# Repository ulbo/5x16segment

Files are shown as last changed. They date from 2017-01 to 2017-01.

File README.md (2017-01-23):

Linkable 5x16-Segment LED Display Module
========================================

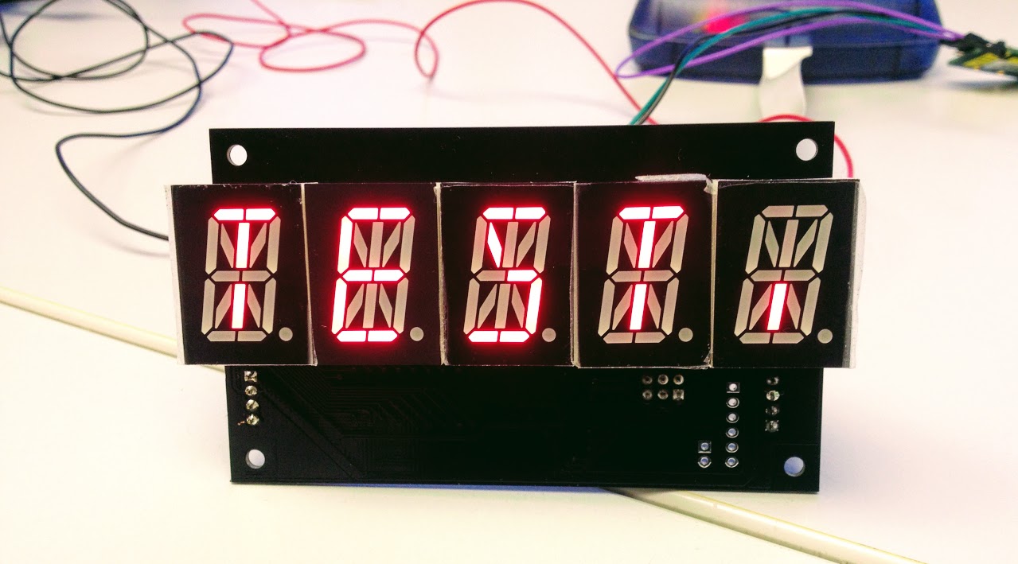
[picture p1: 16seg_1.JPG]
Single 5x16 display board

Single display board

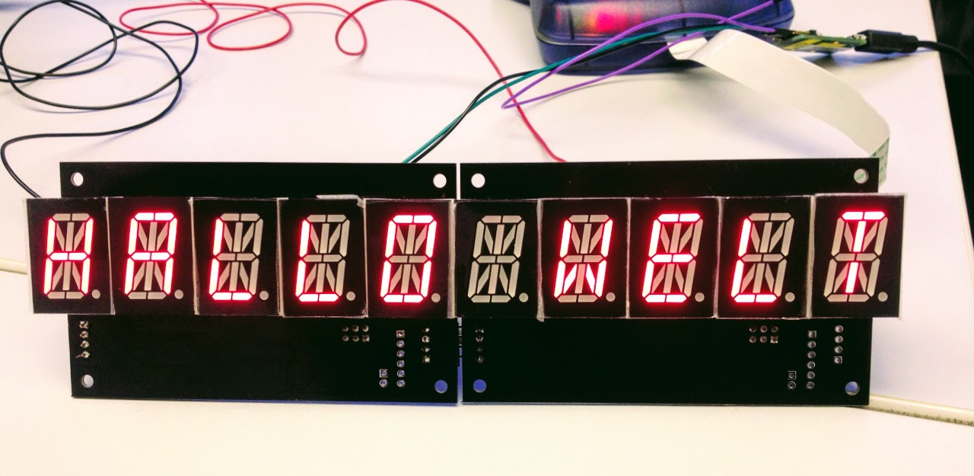
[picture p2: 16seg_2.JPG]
Two boards connected

Two boards connected to form a 10 character display

Hardware
--------

The module uses an Atmel ATmega32 MCU to control all LED segments. Input is done via RS232 interface with a voltage level of 5V.

Supply voltage: 5VDC, max. 200mA per module

Board layout is designed using KiCAD. It is tested for LDS8103-AX 16-segment displays (see /board/lds-8103.jpg), but should work with any common-cathode 16-segment display with same mechanical dimensions and pinout, e.g. Kingbright PSC08-11GWA. Because all pins, except the cathode at pin 11, are directly controlled by the MCU, LEDs with other pinouts can be used with adapted firmware.

Please note: The LED displays are soldered on the opposite board site than the ATmega.

Firmware
--------

Communication to modules is unidirectional with _9600 bps, 8N1_. Modules are daisy-chained, the RS232 output of the leftmost module is connected to the input of its right neighbour. Every module displays all incoming ASCII characters. If its 5-character memory is full, it passes all further incoming chars to its output, where it is received by the next display.

There are a few control characters, which are always passed immediately:

 * 0x01..0x06 : set display brightness, 1 is lowest
 * 0x10, 0x13 : <CR> or <LF> character reset the "cursor" to leftmost position

Compilation under Windows by Atmel Studio 7, Project file: /firmware/16segment.atsln
For Linux, /firmware/makefile is provided, see instructions there.

Firmware is flashed using the standard 6-pin ISP connector. File is /firmware/Release/16segment.hex

Fuse settings:

 * BODLEVEL = 2.7 V,
 * CLKSEL = Ext. Crystal, 8.0-16.0 MHz, 16K CK, 65ms start up time
 * BOOTSZ = 256 words
 * SPIEN enabled
 * TAGEN disabled
 * others: disabled

Character Set
-------------

 * 0x20 .. 0x7F : normal ASCII characters, small caps are currently rendered uppercase (may be changed in future release)
 * 0x80 .. 0x9F : a few "graphic" characters, arrows, etc.
 * 0xA0 .. 0xff : same as 0x20..0x7f, but with decimal point on

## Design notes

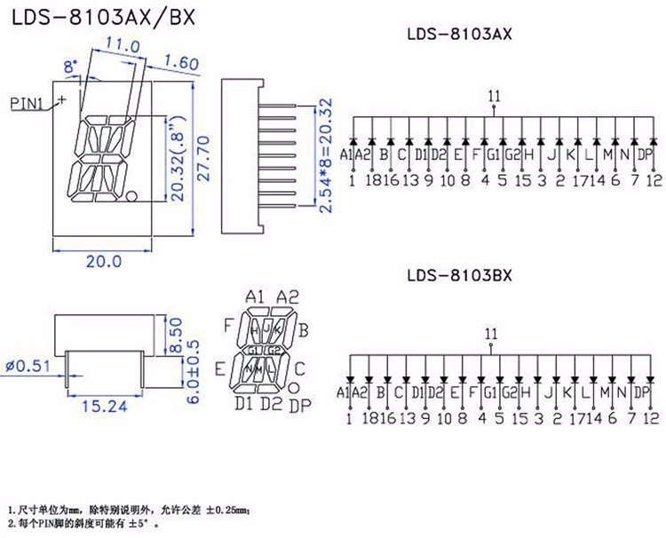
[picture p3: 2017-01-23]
board/lds-8103.jpg

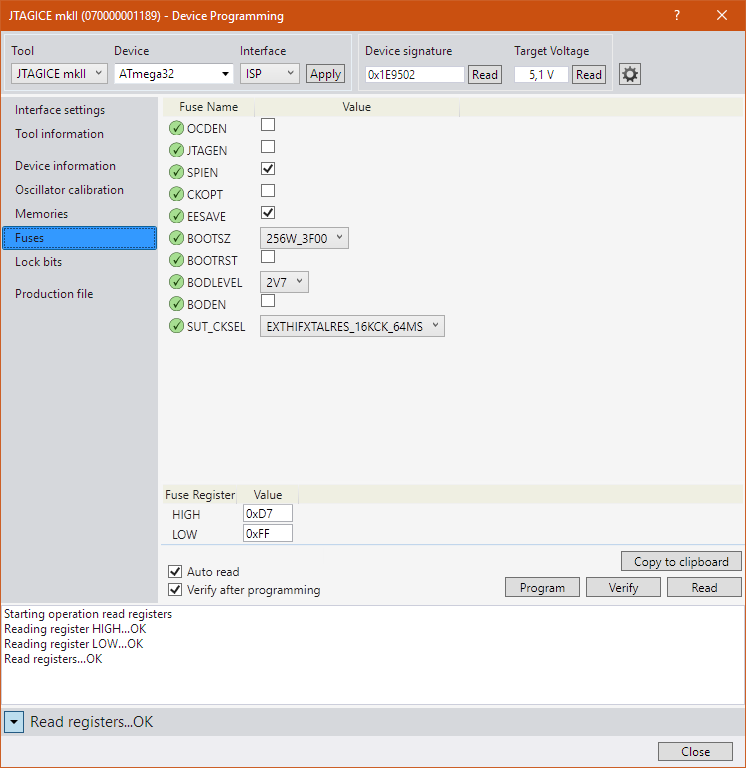
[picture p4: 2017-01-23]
firmware/16seg_fuses.png

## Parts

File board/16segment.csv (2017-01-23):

ID | Bezeichner | Gehäuse | Stückzahl | Bezeichnung | Anbieter und Ref.
1 | LED5,LED2,LED4,LED1,LED3 | LDS8103-AX_rev | 5 | LDS-8103AX
2 | R2,R3,R4,R5,R6,R7,R8,R9,R10,R11,R12,R13,R14,R15,R16,R17,R18 | R_0603_HandSoldering | 17 | 180
3 | C1,C2 | C_0805_HandSoldering | 2 | 15pF
4 | C3,C4,C5,C6,C7 | C_0603_HandSoldering | 5 | 100nF
5 | C8 | C_1210_HandSoldering | 1 | 10uF
6 | IC1 | TQFP-44_10x10mm_Pitch0.8mm | 1 | ATMEGA16-A
7 | P1 | Pin_Header_Straight_1x06 | 1 | CONN_01X06
8 | P2 | Pin_Header_Straight_2x03 | 1 | AVR ISP
9 | P3 | Pin_Header_Angled_1x04 | 1 | DATA_IN
10 | P4 | Pin_Header_Angled_1x04 | 1 | DATA_OUT
11 | Q1,Q2,Q3,Q4,Q5 | SOT-23_Handsoldering | 5 | BC817-40
12 | R1 | R_0603_HandSoldering | 1 | 10k
13 | R19,R20,R21,R22,R23 | R_0603_HandSoldering | 5 | 470
14 | X1 | Q_49U3HMS | 1 | 16 MHz
15 | REF**,REF**,REF**,REF** | MountingHole_3.2mm_M3 | 4 | MountingHole_3.2mm_M3
16 | P5 | Pin_Header_Straight_1x02 | 1 | CONN_01X02

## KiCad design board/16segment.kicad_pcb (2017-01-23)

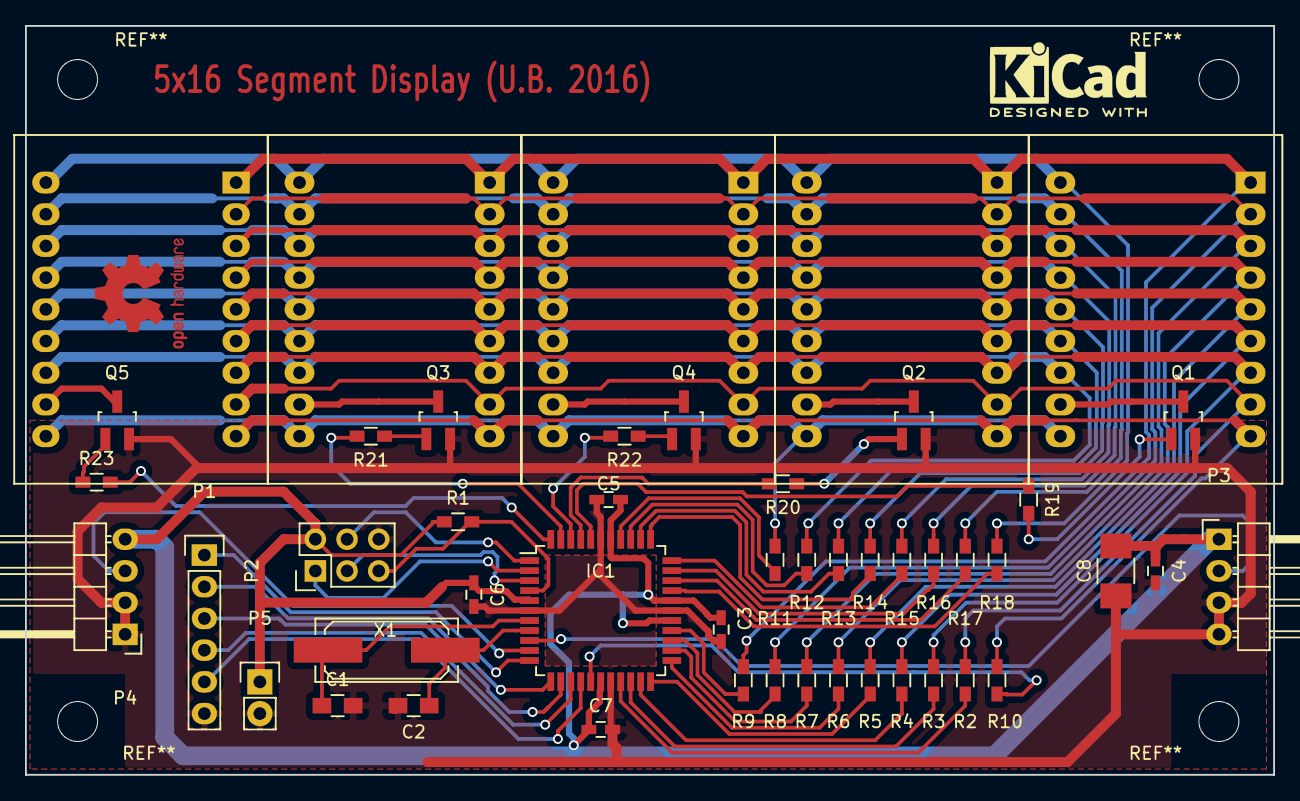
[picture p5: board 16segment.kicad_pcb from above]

Board: 2 copper layers, 100.0 x 60.0 mm, 48 parts (0 on the bottom side), 64 nets.

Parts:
C1, C2: 15pF; C_0805_HandSoldering
C3, C4, C5, C6, C7: 100nF; C_0603_HandSoldering
C8: 10uF; C_1210_HandSoldering
IC1: ATMEGA16-A; TQFP-44_10x10mm_Pitch0.8mm
LED1, LED2, LED3, LED4, LED5: LDS-8103AX; LDS8103-AX_rev
P1: CONN_01X06; Pin_Header_Straight_1x06
P2: AVR ISP; Pin_Header_Straight_2x03
P3: DATA_IN; Pin_Header_Angled_1x04
P4: DATA_OUT; Pin_Header_Angled_1x04
P5: CONN_01X02; Pin_Header_Straight_1x02
Q1, Q2, Q3, Q4, Q5: BC817-40; SOT-23_Handsoldering
R1: 10k; R_0603_HandSoldering
R2, R3, R4, R5, R6, R7, R8, R9, R10, R11, R12, R13, R14, R15, R16, R17, R18: 180; R_0603_HandSoldering
R19, R20, R21, R22, R23: 470; R_0603_HandSoldering
X1: 16 MHz; Q_49U3HMS

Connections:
/LED_1: IC1.40, R19.2
/LED_2: IC1.41, R20.2
/LED_3: IC1.42, R22.2
/LED_4: IC1.43, R21.2
/LED_5: IC1.44, R23.2
/LED_A1: LED1.1, LED2.1, LED3.1, LED4.1, LED5.1, R9.1
/LED_A2: LED1.18, LED2.18, LED3.18, LED4.18, LED5.18, R18.1
/LED_B: LED1.16, LED2.16, LED3.16, LED4.16, LED5.16, R16.1
/LED_C: LED1.13, LED2.13, LED3.13, LED4.13, LED5.13, R13.1
/LED_D1: LED1.9, LED2.9, LED3.9, LED4.9, LED5.9, R10.1
/LED_D2: LED1.10, LED2.10, LED3.10, LED4.10, LED5.10, R11.1
/LED_DP: LED1.12, LED2.12, LED3.12, LED4.12, LED5.12, R12.1
/LED_E: LED1.8, LED2.8, LED3.8, LED4.8, LED5.8, R2.1
/LED_F: LED1.4, LED2.4, LED3.4, LED4.4, LED5.4, R6.1
/LED_G1: LED1.5, LED2.5, LED3.5, LED4.5, LED5.5, R5.1
/LED_G2: LED1.15, LED2.15, LED3.15, LED4.15, LED5.15, R15.1
/LED_H: LED1.3, LED2.3, LED3.3, LED4.3, LED5.3, R7.1
/LED_J: LED1.2, LED2.2, LED3.2, LED4.2, LED5.2, R8.1
/LED_K: LED1.17, LED2.17, LED3.17, LED4.17, LED5.17, R17.1
/LED_L: LED1.14, LED2.14, LED3.14, LED4.14, LED5.14, R14.1
/LED_M: LED1.6, LED2.6, LED3.6, LED4.6, LED5.6, R4.1
/LED_N: LED1.7, LED2.7, LED3.7, LED4.7, LED5.7, R3.1
/MISO: IC1.2, P2.1
/MOSI: IC1.1, P2.4
/RESET: IC1.4, P2.5, R1.2
/RxD: IC1.9, P3.2
/SCK: IC1.3, P2.3
/TxD: IC1.10, P4.3
GND: C1.2, C2.2, C3.2, C4.2, C5.2, C6.2, C7.2, C8.2, IC1.6, IC1.18, IC1.28, IC1.39, P1.6, P2.6, P3.3, P3.4, P4.1, P4.2, P5.2, Q1.2, Q2.2, Q3.2, Q4.2, Q5.2
unnamed: C1.1, IC1.7, X1.1
unnamed: C2.1, IC1.8, X1.2
unnamed: IC1.11, P1.1
unnamed: IC1.12, P1.2
unnamed: IC1.13, P1.3
unnamed: IC1.14, P1.4
unnamed: IC1.15, P1.5
unnamed: IC1.16, R10.2
unnamed: IC1.19, R2.2
unnamed: IC1.20, R3.2
unnamed: IC1.21, R4.2
unnamed: IC1.22, R5.2
unnamed: IC1.23, R6.2
unnamed: IC1.24, R7.2
unnamed: IC1.25, R8.2
unnamed: IC1.26, R9.2
unnamed: IC1.30, R18.2
unnamed: IC1.31, R17.2
unnamed: IC1.32, R16.2
unnamed: IC1.33, R15.2
unnamed: IC1.34, R14.2
unnamed: IC1.35, R13.2
unnamed: IC1.36, R12.2
unnamed: IC1.37, R11.2
unnamed: LED1.11, Q1.3
unnamed: LED2.11, Q2.3
unnamed: LED3.11, Q3.3
unnamed: LED4.11, Q4.3
unnamed: LED5.11, Q5.3
unnamed: Q1.1, R19.1
unnamed: Q2.1, R20.1
unnamed: Q3.1, R21.1
unnamed: Q4.1, R22.1
unnamed: Q5.1, R23.1
VCC: C3.1, C4.1, C5.1, C6.1, C7.1, C8.1, IC1.5, IC1.17, IC1.27, IC1.29, IC1.38, P2.2, P3.1, P4.4, P5.1, R1.1

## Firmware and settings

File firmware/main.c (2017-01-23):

/**********************  P r o g r a m  -  M o d u l e ***********************/
/*!
 *        \file  main.c
 *
 *      \author  Ulrich Bogensperger
 *        $Date: $
 *    $Revision: $
 *
 *        \brief
 *
 *          Firmware for 5x16 segment display board
 *
 *          Chip type           : ATmega16 or ATmega32
 *          Clock frequency     : 16.000 MHz
 *
 *          Fuse settings: BODLEVEL = 2.7 V,
 *                         CLKSEL = Ext. Crystal, 8.0-16.0 MHz, 16K CK, 65ms start up time
 *                         BOOTSZ = 256 words
 *                         SPIEN enabled
 *                         JTAGEN disabled
 *                         others: disabled
 *
 *          Compiler (Atmel Studio 7):
 *              avr-gcc (AVR_8_bit_GNU_Toolchain_3.5.0_1662) 4.9.2
 *
 *          Compiler options:
 *              -Wall -funsigned-char -funsigned-bitfields -ffunction-sections 
 *              -fdata-sections -fpack-struct -fshort-enums -mmcu=atmega32 -Os 
 *
 *          Include Path:
 *              - C:\Program Files (x86)\Atmel\Studio\7.0\Packs\atmel\ATmega_DFP\1.0.90\include
 *
 *          Library Path:
 *              - C:\Program Files (x86)\Atmel\Studio\7.0\
 *
 *-------------------------------[ History ]---------------------------------
 *
 * $Log: $
 *
 *
 *---------------------------------------------------------------------------
 * (c) Copyright 2016, 2017 by Ulrich Bogensperger, Nuernberg, Germany
 ****************************************************************************/

#include "16seg.h"


/*--------------------------------------+
|   DEFINES                             |
+--------------------------------------*/
#define BRIGHT_STEPS        6                   /**< number of brightness steps */
#define BRIGHT_CT_MAX       (1 << BRIGHT_STEPS) /**< brightness counter max */

/*--------------------------------------+
|   TYPEDEFS                            |
+--------------------------------------*/
/* none */

/*--------------------------------------+
|   PROTOTYPES                          |
+--------------------------------------*/
/* none */

/*--------------------------------------+
|   GLOBALS                             |
+--------------------------------------*/
volatile uint16_t G_tick;               /**< system tick, incremented every 10ms */

uint8_t G_led_buffer[NLED][3];          /**< Buffer for LED segments to light. 
                                             Contains the values to be written to GPIOs. */

volatile uint8_t G_brightness = 5;      /**< display brightness 0..5 */
volatile uint8_t G_write_pos;           /**< current write position in G_led_buffer */

/** character table for 16 segment LED display */

/* 
 Port A:   7  6  5  4  3  2  1  0   Port C:  7  6  5  4  3  2  1  0   Port D:  7
 Segment:  A2 K  B G2  L  C DP D2            A1 J  H  F G1  M  N  E            D1
*/

const uint8_t G_chartable[0x80][3] PROGMEM = {
    { 0b00000000, 0b00000000, 0b00000000 },     /* 0x20  <space> */
    { 0b11000000, 0b10100100, 0b00000000 },     /* 0x21  ! */
    { 0b00000000, 0b01010000, 0b00000000 },     /* 0x22  " */
    { 0b00110101, 0b01001100, 0b10000000 },     /* 0x23  # */
    { 0b10010101, 0b11011100, 0b10000000 },     /* 0x24  $ */
    { 0b01011100, 0b00111010, 0b00000000 },     /* 0x25  % */
    { 0b11001101, 0b10101001, 0b10000000 },     /* 0x26  & */
    { 0b00000000, 0b01000000, 0b00000000 },     /* 0x27  ' */
    { 0b01001000, 0b00000000, 0b00000000 },     /* 0x28  ( */
    { 0b00000000, 0b00100010, 0b00000000 },     /* 0x29  ) */
    { 0b01011000, 0b01101110, 0b00000000 },     /* 0x2a  * */
    { 0b00010000, 0b01001100, 0b00000000 },     /* 0x2b  + */
    { 0b00000000, 0b00000010, 0b00000000 },     /* 0x2c  , */
    { 0b00010000, 0b00001000, 0b00000000 },     /* 0x2d  - */
    { 0b00000000, 0b00000100, 0b00000000 },     /* 0x2e  . */
    { 0b01000000, 0b00000010, 0b00000000 },     /* 0x2f  / */

    { 0b11100101, 0b10010011, 0b10000000 },     /* 0x30  0 */
    { 0b00100100, 0b00000000, 0b00000000 },     /* 0x31  1 */
    { 0b10110001, 0b10001001, 0b10000000 },     /* 0x32  2 */
    { 0b10110101, 0b10001000, 0b10000000 },     /* 0x33  3 */
    { 0b00110100, 0b00011000, 0b00000000 },     /* 0x34  4 */
    { 0b10010101, 0b10011000, 0b10000000 },     /* 0x35  5 */
    { 0b10010101, 0b10011001, 0b10000000 },     /* 0x36  6 */
    { 0b10100100, 0b10010000, 0b00000000 },     /* 0x37  7 */
    { 0b10110101, 0b10011001, 0b10000000 },     /* 0x38  8 */
    { 0b10110101, 0b10011000, 0b10000000 },     /* 0x39  9 */
    { 0b00000000, 0b01000100, 0b00000000 },     /* 0x3a  : */
    { 0b00000000, 0b01000010, 0b00000000 },     /* 0x3b  ; */
    { 0b01000001, 0b00000010, 0b10000000 },     /* 0x3c  < */
    { 0b00010001, 0b00001000, 0b10000000 },     /* 0x3d  = */
    { 0b00001001, 0b00100000, 0b10000000 },     /* 0x3e  > */
    { 0b10110000, 0b10000100, 0b00000000 },     /* 0x3f  ? */

    { 0b00100101, 0b10010101, 0b00000000 },     /* 0x40  @ */
    { 0b10110100, 0b10011001, 0b00000000 },     /* 0x41  A */
    { 0b11010101, 0b10011001, 0b10000000 },     /* 0x42  B */
    { 0b10000001, 0b10010001, 0b10000000 },     /* 0x43  C */
    { 0b10100101, 0b11000100, 0b10000000 },     /* 0x44  D */
    { 0b10010001, 0b10011001, 0b10000000 },     /* 0x45  E */
    { 0b10010000, 0b10011001, 0b00000000 },     /* 0x46  F */
    { 0b10010101, 0b10010001, 0b10000000 },     /* 0x47  G */
    { 0b00110100, 0b00011001, 0b00000000 },     /* 0x48  H */
    { 0b10000001, 0b11000100, 0b10000000 },     /* 0x49  I */
    { 0b00100101, 0b00000001, 0b10000000 },     /* 0x4a  J */
    { 0b01001000, 0b00011001, 0b00000000 },     /* 0x4b  K */
    { 0b00000001, 0b00010001, 0b10000000 },     /* 0x4c  L */
    { 0b01100100, 0b00110001, 0b00000000 },     /* 0x4d  M */
    { 0b00101100, 0b00110001, 0b00000000 },     /* 0x4e  N */
    { 0b10100101, 0b10010001, 0b10000000 },     /* 0x4f  O */

    { 0b10110000, 0b10011001, 0b00000000 },     /* 0x50  P */
    { 0b10101101, 0b10010001, 0b10000000 },     /* 0x51  Q */
    { 0b10111000, 0b10011001, 0b00000000 },     /* 0x52  R */
    { 0b10010101, 0b10100000, 0b10000000 },     /* 0x53  S */
    { 0b10000000, 0b11000100, 0b00000000 },     /* 0x54  T */
    { 0b00100101, 0b00010001, 0b10000000 },     /* 0x55  U */
    { 0b01000000, 0b00010011, 0b00000000 },     /* 0x56  V */
    { 0b00101100, 0b00010011, 0b00000000 },     /* 0x57  W */
    { 0b01001000, 0b00100010, 0b00000000 },     /* 0x58  X */
    { 0b01000000, 0b00100100, 0b00000000 },     /* 0x59  Y */
    { 0b11000001, 0b10000010, 0b10000000 },     /* 0x5a  Z */
    { 0b10000001, 0b01000100, 0b00000000 },     /* 0x5b  [ */
    { 0b00001000, 0b00100000, 0b00000000 },     /* 0x5c  \ */
    { 0b00000000, 0b11000100, 0b10000000 },     /* 0x5d  ] */
    { 0b00000000, 0b00110000, 0b00000000 },     /* 0x5e  ^ */
    { 0b00000001, 0b00000000, 0b10000000 },     /* 0x5f  _ */

    { 0b01000000, 0b00000000, 0b00000000 },     /* 0x60  <backtick> */
    { 0b10110100, 0b10011001, 0b00000000 },     /* 0x61  a */ /* small caps have same glyphs as large caps */
    { 0b11010101, 0b10011001, 0b10000000 },     /* 0x62  b */
    { 0b10000001, 0b10010001, 0b10000000 },     /* 0x63  c */
    { 0b10100101, 0b11000100, 0b10000000 },     /* 0x64  d */
    { 0b10010001, 0b10011001, 0b10000000 },     /* 0x65  e */
    { 0b10010000, 0b10011001, 0b00000000 },     /* 0x66  f */
    { 0b10010101, 0b10010001, 0b10000000 },     /* 0x67  g */
    { 0b00110100, 0b00011001, 0b00000000 },     /* 0x68  h */
    { 0b10000001, 0b11000100, 0b10000000 },     /* 0x69  i */
    { 0b00100101, 0b00000001, 0b10000000 },     /* 0x6a  j */
    { 0b01001000, 0b00011001, 0b00000000 },     /* 0x6b  k */
    { 0b00000001, 0b00010001, 0b10000000 },     /* 0x6c  l */
    { 0b01100100, 0b00110001, 0b00000000 },     /* 0x6d  m */
    { 0b00101100, 0b00110001, 0b00000000 },     /* 0x6e  n */
    { 0b10100101, 0b10010001, 0b10000000 },     /* 0x6f  o */

    { 0b10110000, 0b10011001, 0b00000000 },     /* 0x70  p */
    { 0b10101101, 0b10010001, 0b10000000 },     /* 0x71  q */
    { 0b10111000, 0b10011001, 0b00000000 },     /* 0x72  r */
    { 0b10010101, 0b10100000, 0b10000000 },     /* 0x73  s */
    { 0b10000000, 0b11000100, 0b00000000 },     /* 0x74  t */
    { 0b00100101, 0b00010001, 0b10000000 },     /* 0x75  u */
    { 0b01000000, 0b00010011, 0b00000000 },     /* 0x76  v */
    { 0b00101100, 0b00010011, 0b00000000 },     /* 0x77  w */
    { 0b01001000, 0b00100010, 0b00000000 },     /* 0x78  x */
    { 0b01000000, 0b00100100, 0b00000000 },     /* 0x79  y */
    { 0b11000001, 0b10000010, 0b10000000 },     /* 0x7a  z */
    { 0b10000001, 0b01001100, 0b00000000 },     /* 0x7b  { */
    { 0b00000000, 0b00010001, 0b00000000 },     /* 0x7c  | */
    { 0b00010000, 0b11000100, 0b10000000 },     /* 0x7d  } */
    { 0b00110000, 0b00110000, 0b00000000 },     /* 0x7e  ~ */
    { 0b11111111, 0b11111111, 0b00000000 },     /* 0x7f  <all segments> */
        
    /* 0x80..0x9f graphic characters */
    { 0b00000000, 0b01000000, 0b00000000 },     /* 0x80  <North> */
    { 0b01000000, 0b00000000, 0b00000000 },     /* 0x81  <NE> */
    { 0b00010000, 0b00000000, 0b00000000 },     /* 0x82  <East> */
    { 0b00001000, 0b00000000, 0b00000000 },     /* 0x83  <SE> */
    { 0b00000000, 0b00000100, 0b00000000 },     /* 0x84  <South> */
    { 0b00000000, 0b00000010, 0b00000000 },     /* 0x85  <SW> */
    { 0b00000000, 0b00001000, 0b00000000 },     /* 0x86  <West> */
    { 0b00000000, 0b00100000, 0b00000000 },     /* 0x87  <NW> */

    { 0b00000000, 0b00000000, 0b00000000 },     /* 0x88  <> */  // TODO
    { 0b00000000, 0b00000000, 0b00000000 },     /* 0x89  <> */
    { 0b00000000, 0b00000000, 0b00000000 },     /* 0x8a  <> */
    { 0b00000000, 0b00000000, 0b00000000 },     /* 0x8b  <> */
    { 0b00000000, 0b00000000, 0b00000000 },     /* 0x8c  <> */
    { 0b00000000, 0b00000000, 0b00000000 },     /* 0x8d  <> */
    { 0b00000000, 0b00000000, 0b00000000 },     /* 0x8e  <> */
    { 0b00000000, 0b00000000, 0b00000000 },     /* 0x8f  <> */

    { 0b00000000, 0b00000000, 0b00000000 },     /* 0x90  <> */
    { 0b00000000, 0b00000000, 0b00000000 },     /* 0x91  <> */
    { 0b00000000, 0b00000000, 0b00000000 },     /* 0x92  <> */
    { 0b00000000, 0b00000000, 0b00000000 },     /* 0x93  <> */
    { 0b00000000, 0b00000000, 0b00000000 },     /* 0x94  <> */
    { 0b00000000, 0b00000000, 0b00000000 },     /* 0x95  <> */
    { 0b00000000, 0b00000000, 0b00000000 },     /* 0x96  <> */
    { 0b00000000, 0b00000000, 0b00000000 },     /* 0x97  <> */
    
    { 0b00000000, 0b00000000, 0b00000000 },     /* 0x98  <> */
    { 0b00000000, 0b00000000, 0b00000000 },     /* 0x99  <> */
    { 0b00000000, 0b00000000, 0b00000000 },     /* 0x9a  <> */
    { 0b00000000, 0b00000000, 0b00000000 },     /* 0x9b  <> */
    { 0b00000000, 0b00000000, 0b00000000 },     /* 0x9c  <> */
    { 0b00000000, 0b00000000, 0b00000000 },     /* 0x9d  <> */
    { 0b00000000, 0b00000000, 0b00000000 },     /* 0x9e  <> */
    { 0b00000000, 0b00000000, 0b00000000 },     /* 0x9f  <> */

};
   

/**********************************************************************/
ISR( TIMER0_COMP_vect )
{
    static uint16_t tick = 0;
    static uint8_t led_ix, bright_ct;
    
    /* G_tick is incremented every 10ms */
    if( tick >= TICKS_PER_SEC_0 / 100 ) {
        ++G_tick;
        tick = 0;
    }        

    /* do LED multiplexing */
    
    if( bright_ct < (1 << G_brightness) ) {
        led_on( led_ix );
    
        LED_PORT_1 = G_led_buffer[led_ix][0];
        LED_PORT_2 = G_led_buffer[led_ix][1];
        LED_PORT_3 &= ~LED_D1_M;
        LED_PORT_3 |= G_led_buffer[led_ix][2] & LED_D1_M;
    }
    else {
        leds_off();
    }
    
    if( ++bright_ct >= BRIGHT_CT_MAX ) {
        bright_ct = 0;
        
        if( ++led_ix >= NLED ) {
            led_ix = 0;
        }
    }
}


/**********************************************************************/
/** Calculate LED segments from ASCII char.
 *
 */
void
ascii2segments( uint8_t c, uint8_t *port1, uint8_t *port2, uint8_t *port3 )
{
    if( c < 0x20 ) {
        /* 
         * The first 32 ASCII characters are control characters.
         * These are rendered as blanks.
         */
        *port1 = *port2 = *port3 = 0;
    }
    else if( c < 0xa0 ) {
        /*
         * 0x20..0x7F: Normal ASCII characters. Taken from character table.
         * 0x80..0x9F: A few "graphic" characters here. Also taken from table.
         */
        c -= 0x20;
        *port1 = pgm_read_byte( &G_chartable[c][0] );
        *port2 = pgm_read_byte( &G_chartable[c][1] );
        *port3 = pgm_read_byte( &G_chartable[c][2] );
    }
    else {
        /*
         * Remaining characters are ASCII characters again, 
         * but with decimal point on.
         */
        c -= 0xa0;
        *port1 = pgm_read_byte( &G_chartable[c][0] ) | LED_DP_M;
        *port2 = pgm_read_byte( &G_chartable[c][1] );
        *port3 = pgm_read_byte( &G_chartable[c][2] );
    }
}


/**********************************************************************/
/** Initialize IO ports
 *
 */
void
io_init( void )
{
    /* Port A initialization */
	PORTA = 0;
	DDRA = 0xff;
    
    /* Port B initialization */
    PORTB = 0;
    DDRB = LED_1_M | LED_2_M | LED_3_M | LED_4_M | LED_5_M | PB_UNUSED_M;
    
    /* Port C initialization */
    PORTC = 0;
    DDRC = 0xff;
    
    /* Port D initialization */
	PORTD = TxD_M | RxD_M | AUX_1_M | AUX_2_M | AUX_3_M | AUX_4_M | AUX_5_M | LED_D1_M;
	DDRD = TxD_M | LED_D1_M;
}


/**********************************************************************/
/** Timer 0 initialization
 *
 *  Timer controls the refresh of the 16-segment LEDs.
 *  Brightness is done by PWM. Because its perception is exponential,
 *  we need for e.g. 6 levels a time slot of 1/64 of maximum brightness.
 *
 *  Timing:
 *   - complete refresh (all 5 LEDs): 100Hz = 10ms
 *   - refresh per LED              : 10ms / 5 = 2ms
 *   - 6 brightness levels          : 2ms / 64 = 31.25us
 */
void
timer0_init( void )
{
    /* CTC mode, prescaler 8 */
    TCCR0 = 0x0a;
    TCNT0 = 0x00;
    OCR0 = (F_CPU / 8L / TICKS_PER_SEC_0 ) - 1;

    /* Compare A Match IRQ enable */
    TIMSK = _BV( OCF0 );
}


/**********************************************************************/
/** Initialization of UART for host communication
 *
 *  Simple implementation without using interrupts.
 */
void
uart_init( void )
{
    /*
     * USART initialization ;
     * Communication Parameters: 8 Data, 1 Stop, No Parity ;
     * USART Receiver: On ;
     * USART Transmitter: On ;
     * USART Mode: Asynchronous ;
     * USART Baud Rate: BAUDRATE
     */
    UCSRA = 0x00;
    UCSRB = 0x18;   /* no interrupts */
    UCSRC = 0x06;

    /* 
     * Calculate values for UBRR, see formula in chap. 
     * "USART, Clock Generation" in ATmega32 datasheet 
     */
    UBRRH = (((F_CPU / 16) / BAUDRATE) - 1) >> 8;
    UBRRL = (((F_CPU / 16) / BAUDRATE) - 1) % 0xff;
}


/**********************************************************************/
static inline void
uart_putc( char c )
{
    loop_until_bit_is_set( UCSRA, UDRE );
    UDR = c;
}


/**********************************************************************/
void
handle_uart( void )
{
    uint8_t c;
    
    /* something received ? */
    if( UCSRA & _BV(RXC) ) {
        c = UDR;
        
        /* handle control characters */
        if( IN_RANGE( c, 1, BRIGHT_STEPS) ) {
            /* set display brightness, valid: 1..BRIGHT_STEPS */
            G_brightness = c - 1;
            
            /* forward control character to next display in chain */
            uart_putc( c );
        }
        else if( c == '\n' || c == '\r' ) {
            /* reset write position of display buffer */
            G_write_pos = 0;
            
            /* forward control character */
            uart_putc( c );
            
            /* possible improvement: re-init UART, if no '\n' char was received for 60 seconds */
        }
        else if( c >= 0x20 ) {
            /* printable --> display incoming char */
            
            if( G_write_pos < NLED ) {
                ascii2segments( c,  &G_led_buffer[G_write_pos][0],
                                    &G_led_buffer[G_write_pos][1],
                                    &G_led_buffer[G_write_pos][2] );
                ++G_write_pos;                                    
            }
            else {
                /* forward char to next display in chain */
                uart_putc( c );
            }
        }
    }
}


/**********************************************************************/
int
main(void)
{
    #if ENABLE_WATCHDOG != 0
    wdt_enable( WDTO_250MS );
    #endif

    /* initialize hardware */
    io_init();
    timer0_init();
    uart_init();

    /* interrupts go! */
    sei();

    /* Main Loop */
    for(;;) {
        wdt_reset();
        handle_uart();
    }
    
    return 0;
}

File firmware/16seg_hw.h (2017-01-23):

/*************************  I n c l u d e  -  F i l e ***********************/
/*!
 *        \file  16seg_hw.h
 *
 *      \author  ulrich.bogensperger@
 *        $Date: $
 *    $Revision: $
 *
 *        \brief
 *
 *          Hardware settings for 5x15 segment display board.
 *
 *-------------------------------[ History ]---------------------------------
 *
 * $Log: $
 *
 *---------------------------------------------------------------------------
 * (c) Copyright 2016 by Ulrich Bogensperger, Nuernberg, Germany
 ****************************************************************************/

#ifndef __16SEG_HW_H
#define __16SEG_HW_H

/*--------------------------------------+
|   DEFINES                             |
+--------------------------------------*/

/* Port A */
#define LED_PORT_1          PORTA           /* LED segments */

#define LED_DP_M            0b00000010      /**< bit for decimal point segment */


/* Port B */
#define LED_1_M             0b00000001      /**< select display 1 */
#define LED_2_M             0b00000010      /**< select display 2 */
#define LED_3_M             0b00000100      /**< select display 3 */
#define LED_4_M             0b00001000      /**< select display 4 */
#define LED_5_M             0b00010000      /**< select display 5 */
#define PB_UNUSED_M         0b11100000      /**< unused pins on port B */

#define led_on( n )         do{ PORTB = 1 << (n); }while(0) /* simplification because other pins of PORTB are not used */
#define leds_off()          do{ PORTB = 0; }while(0)


/* Port C */
#define LED_PORT_2          PORTC           /* LED segments */

/* Port D */
#define LED_PORT_3          PORTD           /* used for LED segment D1 only */

#define RxD_M               0b00000001      /**< serial port RxD line */
#define TxD_M               0b00000010      /**< serial port TxD line */
#define AUX_1_M             0b00000100      /**< pin 1 on connector P1 */
#define AUX_2_M             0b00001000      /**< pin 2 on connector P1 */
#define AUX_3_M             0b00010000      /**< pin 3 on connector P1 */
#define AUX_4_M             0b00100000      /**< pin 4 on connector P1 */
#define AUX_5_M             0b01000000      /**< pin 5 on connector P1 */
#define LED_D1_M            0b10000000      /**< LED segment D1 */


/*--------------------------------------+
|   TYPEDEFS                            |
+--------------------------------------*/


/*--------------------------------------+
|   PROTOTYPES                          |
+--------------------------------------*/


#endif /* __16SEG_HW_H */
